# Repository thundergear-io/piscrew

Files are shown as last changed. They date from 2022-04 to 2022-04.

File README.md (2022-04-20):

# Pi Screw
Pi Screw is a shield designed for Raspberry Pi Boards. The purpose of this shield is to make connecting a wide range of wires easier with the help of screw terminals and QWIIC connectors. 

Please refer to our documentation for more information and board compatibility:

https://github.com/thundergear-io/piscrew/blob/main/documentation/piscrew-documentation.pdf

# Front 

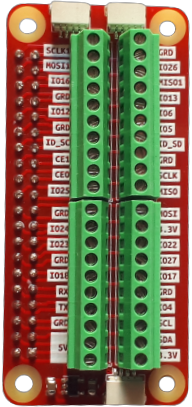
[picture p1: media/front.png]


# Back

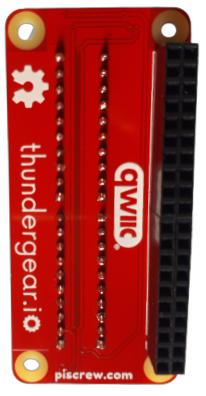
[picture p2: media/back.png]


# Certification



# Contact

Need to contact us ? Send us an email at contact@thundergear.io

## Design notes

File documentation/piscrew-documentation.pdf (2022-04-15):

# PiScrew

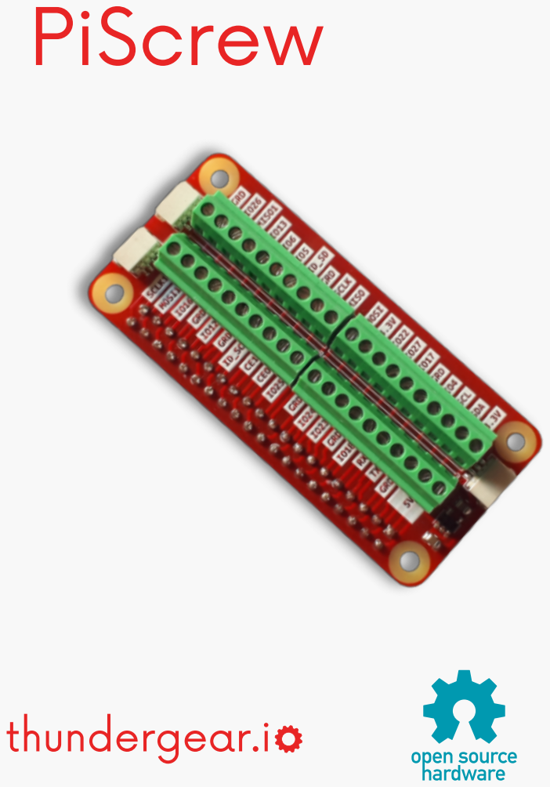
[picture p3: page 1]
thundergear.i

# Table of contents

What is Pi Screw? | 2
What does it help fix? | 2
List of supported Raspberry Pi Boards | 2
Estimated Voltage and Current ratings | 3
Features of Pi Screw | 3
Pictures of Pi Screw | 3

# What is Pi Screw?

Pi Screw is a shield designed for Raspberry Pi Boards. The purpose of this shield is to make connecting a wide range of wires easier with the help of screw terminals and QWIIC connectors.

## What does it help fix?

Most raspberry pi boards require you to use DuPont / Jumper connectors to connect sensors, motor drivers, and so on to the board. The issue with this is that most of them come pre-manufactured.

Those can vary in the amount of copper used to make the wire, the quality of the metal, the quality of the connector, and the manufacturing process of those cables.

The connectors can wear off over time. This can cause electrical connectivity issues with your project. This can result in making you lose time trying to troubleshoot the specific faulty connector(s).

Another issue is that not everyone may have Dupont / Jumper cables on hand. The screw terminals allow you to easily use your own wires. Please see the supported wires gauge in the features section.

Pi Screw fixes these issues by introducing a screw terminal connector with a similar layout to the raspberry pi pinout.

Some boards do not come with pin header slots and thus use an alternative means for the user to interface with them such as solder pads. You can easily solder some wires and directly connect them to your raspberry pi board with the help of Pi Screw’s screw terminals.

## List of supported Raspberry Pi Boards

Model | Compatibility
Pi 1 Model B (2012) | NO
Pi 1 Model A (2013) | NO
Pi 1 Model B+ (2014) | YES
Pi 1 Model A+ (2014) | YES
Pi 2 Model B (2015) | YES
Pi Zero (2015) | YES
Pi 3 Model B (2016) | YES
Pi Zero W (2017) | YES
Pi 3 Model B+ (2018) | YES
Pi 3 Model A+ (2019) | YES
Pi 4 Model A (2019) | YES

Pi 4 Model B (2020) | YES
Pi Zero 2 (2021) | YES

## Estimated Voltage and Current ratings

Please note that these ratings do not apply to what the raspberry pi boards can handle but only to the connectors and copper tracks on the PCB.

MAX VOLTAGE | MAX CURRENT
12V | 1A

## Features of Pi Screw

★ Support for 3 QWIIC ( Sparkfun ) / STEMMA QT ( Adafruit ) boards/sensors
★ Easy use screw terminals
★ Modern and stylish silkscreen labeling
★ Dedicated 3.3V voltage regulator ( 350-500ma ) to power the QWIIC / STEMMA QT connectors

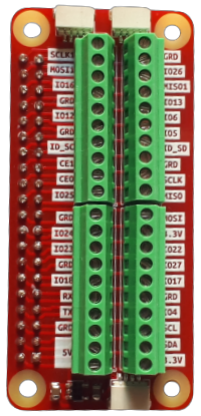
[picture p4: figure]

★ Support for wire gauges 18~26 AWG

## Pictures of Pi Screw

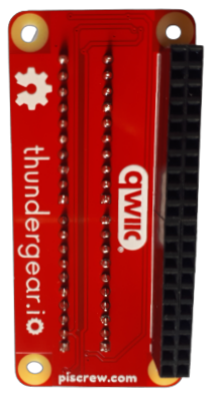
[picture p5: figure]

FRONT | BACK

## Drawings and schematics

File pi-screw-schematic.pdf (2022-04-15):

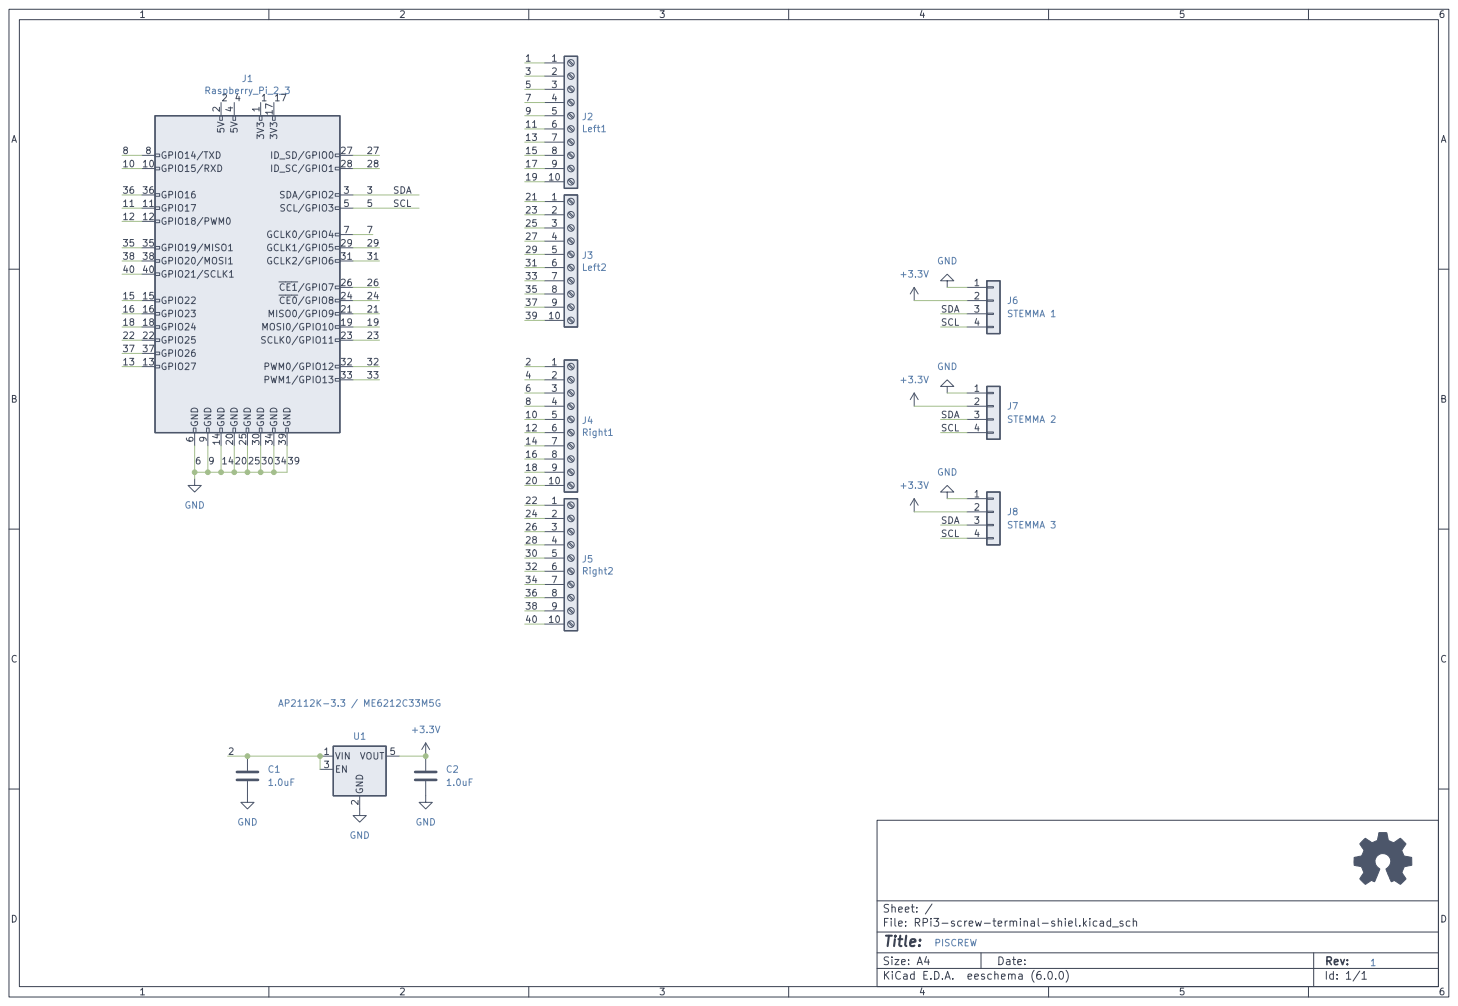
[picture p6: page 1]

File: RPi3-screw-terminal-shiel.kicad_sch Sheet: /

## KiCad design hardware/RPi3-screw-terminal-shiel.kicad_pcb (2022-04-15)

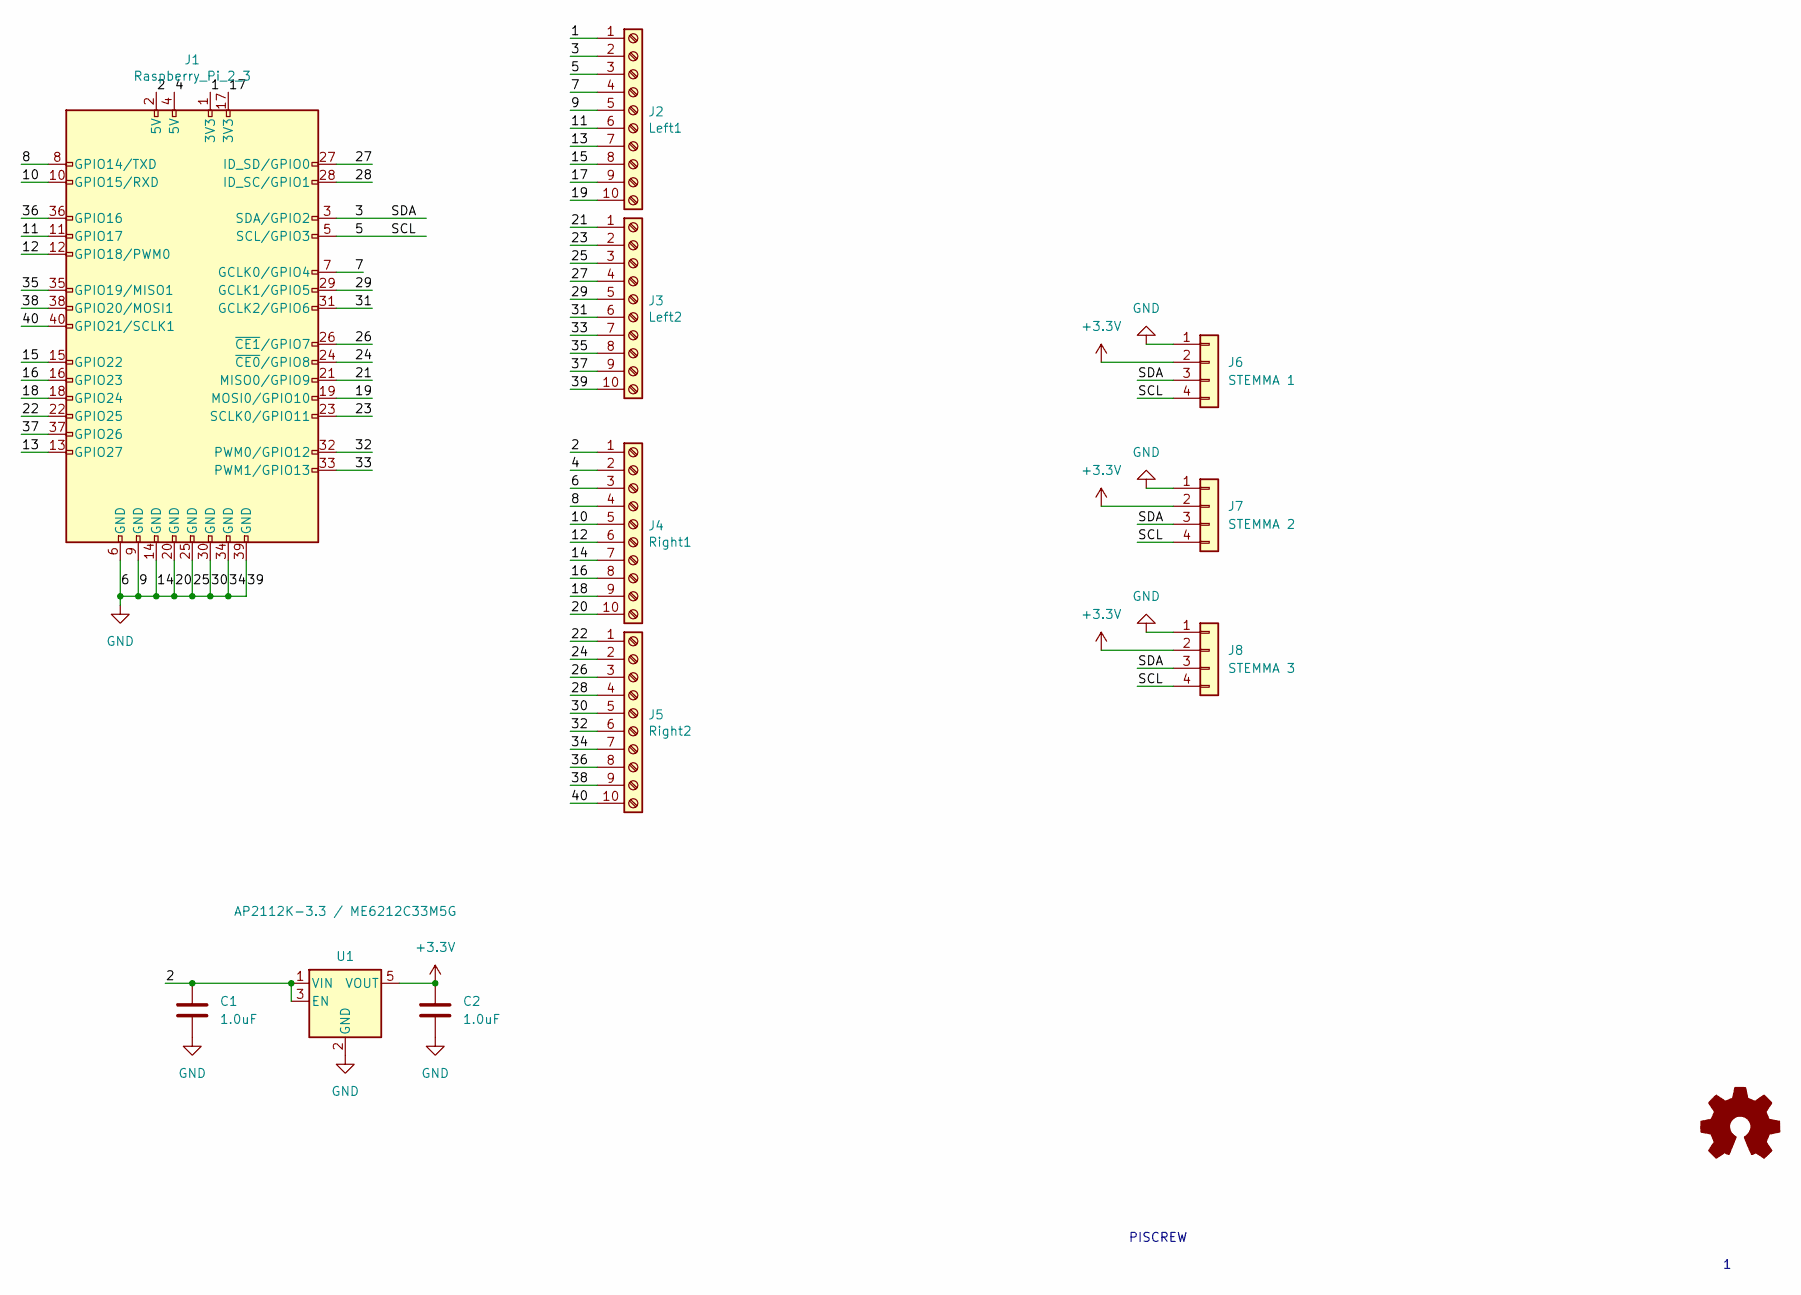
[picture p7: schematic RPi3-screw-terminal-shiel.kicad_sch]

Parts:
C1, C2: 1.0uF
J1: Raspberry_Pi_2_3
J2: Left1
J3: Left2
J4: Right1
J5: Right2
J6: STEMMA 1
J7: STEMMA 2
J8: STEMMA 3
U1: AP2112K-3.3 / ME6212C33M5G; SOT-23-5

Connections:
+3V3: C2.1, J6.2, J7.2, J8.2, U1.5 (VOUT)
/1: J1.1 (3V3), J2.1
/2: C1.1, J1.2 (5V), J4.1, U1.1 (VIN), U1.3 (EN)
/3: J1.3 (SDA/GPIO2), J2.2, J6.3, J7.3, J8.3
/4: J1.4 (5V), J4.2
/5: J1.5 (SCL/GPIO3), J2.3, J6.4, J7.4, J8.4
/7: J1.7 (GCLK0/GPIO4), J2.4
/8: J1.8 (GPIO14/TXD), J4.4
/10: J1.10 (GPIO15/RXD), J4.5
/11: J1.11 (GPIO17), J2.6
/12: J1.12 (GPIO18/PWM0), J4.6
/13: J1.13 (GPIO27), J2.7
/15: J1.15 (GPIO22), J2.8
/16: J1.16 (GPIO23), J4.8
/17: J1.17 (3V3), J2.9
/18: J1.18 (GPIO24), J4.9
/19: J1.19 (MOSI0/GPIO10), J2.10
/21: J1.21 (MISO0/GPIO9), J3.1
/22: J1.22 (GPIO25), J5.1
/23: J1.23 (SCLK0/GPIO11), J3.2
/24: J1.24 (~CE0/GPIO8), J5.2
/26: J1.26 (~CE1/GPIO7), J5.3
/27: J1.27 (ID_SD/GPIO0), J3.4
/28: J1.28 (ID_SC/GPIO1), J5.4
/29: J1.29 (GCLK1/GPIO5), J3.5
/31: J1.31 (GCLK2/GPIO6), J3.6
/32: J1.32 (PWM0/GPIO12), J5.6
/33: J1.33 (PWM1/GPIO13), J3.7
/35: J1.35 (GPIO19/MISO1), J3.8
/36: J1.36 (GPIO16), J5.8
/37: J1.37 (GPIO26), J3.9
/38: J1.38 (GPIO20/MOSI1), J5.9
/40: J1.40 (GPIO21/SCLK1), J5.10
GND: C1.2, C2.2, J1.6 (GND), J1.9 (GND), J1.14 (GND), J1.20 (GND), J1.25 (GND), J1.30 (GND), J1.34 (GND), J1.39 (GND), J2.5, J3.3, J3.10, J4.3, J4.7, J4.10, J5.5, J5.7, J6.1, J7.1, J8.1, U1.2 (GND)

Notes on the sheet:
PISCREW

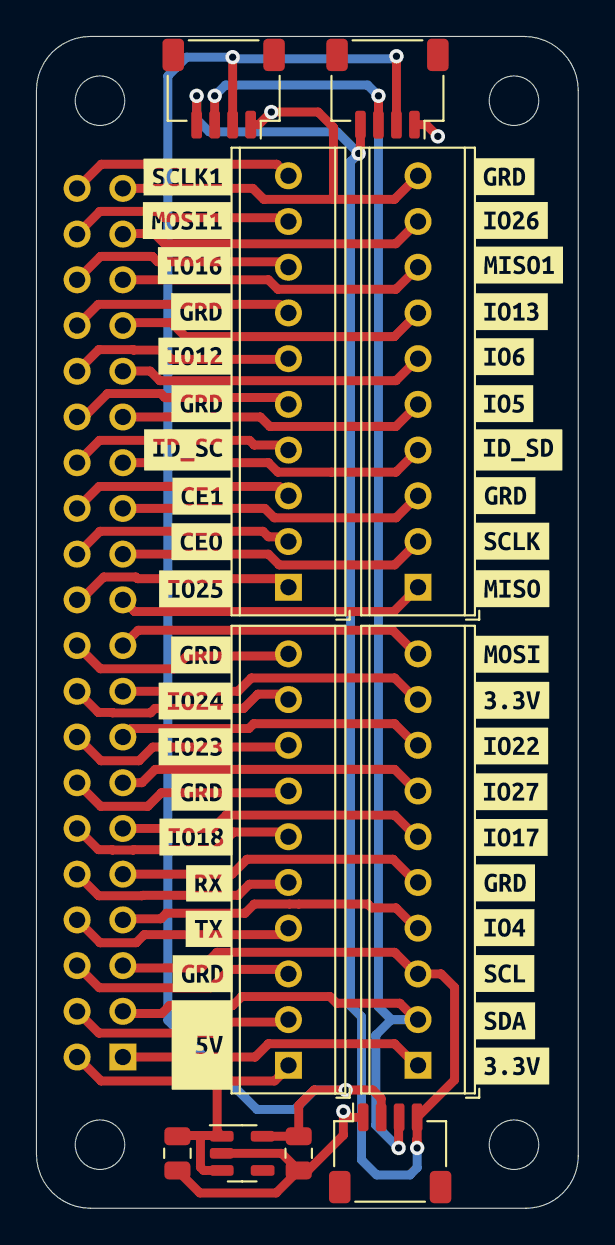
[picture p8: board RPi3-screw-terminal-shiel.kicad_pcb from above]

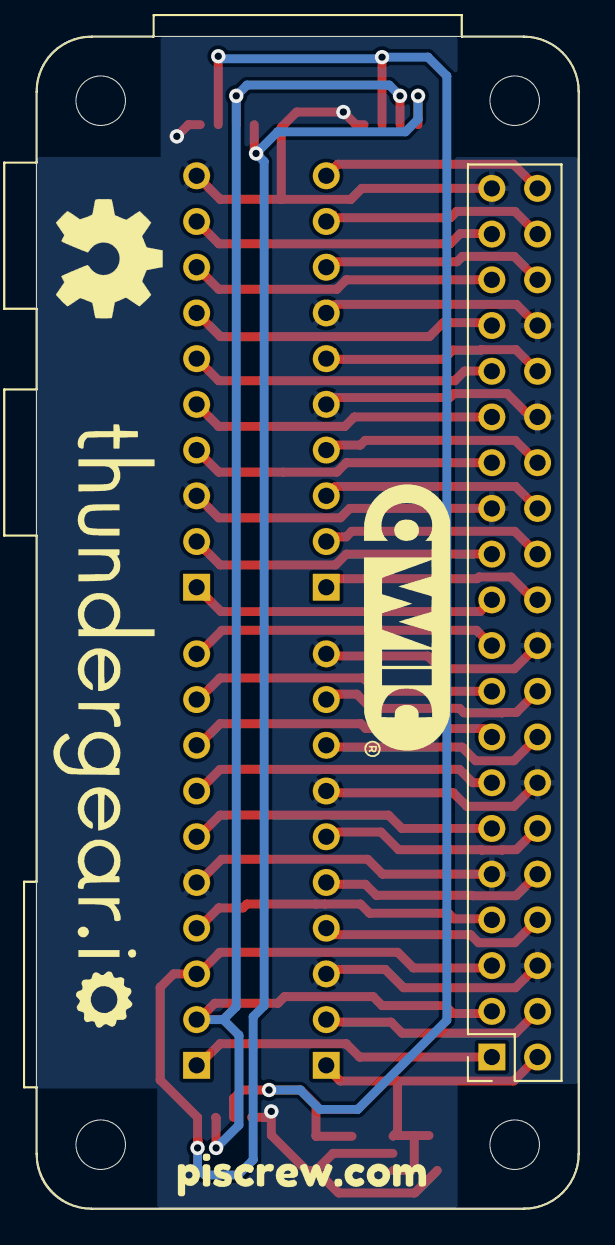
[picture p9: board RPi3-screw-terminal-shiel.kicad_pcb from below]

Board: 2 copper layers, 30.1 x 65.1 mm, 51 parts (2 on the bottom side), 34 nets.

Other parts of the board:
kibuzzard-61EAB5A7: G***; kibuzzard-61EAB5A7
kibuzzard-61EAB5AF: G***; kibuzzard-61EAB5AF
kibuzzard-61EAB5B7: G***; kibuzzard-61EAB5B7
kibuzzard-61EAB5BF: G***; kibuzzard-61EAB5BF
kibuzzard-61EAB5C9: G***; kibuzzard-61EAB5C9
kibuzzard-61EAB5E7: G***; kibuzzard-61EAB5E7
kibuzzard-61EAB7AC: G***; kibuzzard-61EAB7AC
kibuzzard-61EAB7BB: G***; kibuzzard-61EAB7BB
kibuzzard-61EAB7C8: G***; kibuzzard-61EAB7C8
kibuzzard-61EAB7D1: G***; kibuzzard-61EAB7D1
kibuzzard-61EAB7DA: G***; kibuzzard-61EAB7DA
kibuzzard-61EAB8A6: G***; kibuzzard-61EAB8A6
kibuzzard-61EAB8B0: G***; kibuzzard-61EAB8B0
kibuzzard-61EAB44C: G***; kibuzzard-61EAB44C
kibuzzard-61EAB46F: G***; kibuzzard-61EAB46F
kibuzzard-61EAB52D: G***; kibuzzard-61EAB52D
kibuzzard-61EAB57E: G***; kibuzzard-61EAB57E
kibuzzard-61EAB58D: G***; kibuzzard-61EAB58D
kibuzzard-61EAB59E: G***; kibuzzard-61EAB59E
kibuzzard-61EAB79F: G***; kibuzzard-61EAB79F
kibuzzard-61EAB88A: G***; kibuzzard-61EAB88A
kibuzzard-61EAB89C: G***; kibuzzard-61EAB89C
kibuzzard-61EAB517: G***; kibuzzard-61EAB517
kibuzzard-61EAB524: G***; kibuzzard-61EAB524
kibuzzard-61EAB538: G***; kibuzzard-61EAB538
kibuzzard-61EAB545: G***; kibuzzard-61EAB545
kibuzzard-61EAB559: G***; kibuzzard-61EAB559
kibuzzard-61EAB567: G***; kibuzzard-61EAB567
kibuzzard-61EAB573: G***; kibuzzard-61EAB573
kibuzzard-61EAB596: G***; kibuzzard-61EAB596
kibuzzard-61EAB753: G***; kibuzzard-61EAB753
kibuzzard-61EAB790: G***; kibuzzard-61EAB790
kibuzzard-61EAB798: G***; kibuzzard-61EAB798
kibuzzard-61EAB879: G***; kibuzzard-61EAB879
kibuzzard-61EAB880: G***; kibuzzard-61EAB880
kibuzzard-61EAB894: G***; kibuzzard-61EAB894
kibuzzard-61EAD2A5: G***; kibuzzard-61EAD2A5
kibuzzard-61EAD2B4: G***; kibuzzard-61EAD2B4
kibuzzard-61EAD2FB: G***; kibuzzard-61EAD2FB
kibuzzard-6217C81B: G***; kibuzzard-6217C81B
